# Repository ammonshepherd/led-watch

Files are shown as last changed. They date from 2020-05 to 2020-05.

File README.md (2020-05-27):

# LED Watch
My attempt at making a watch using LEDs in place of the numbers. The color of the LED denotes the hour, minute or second.

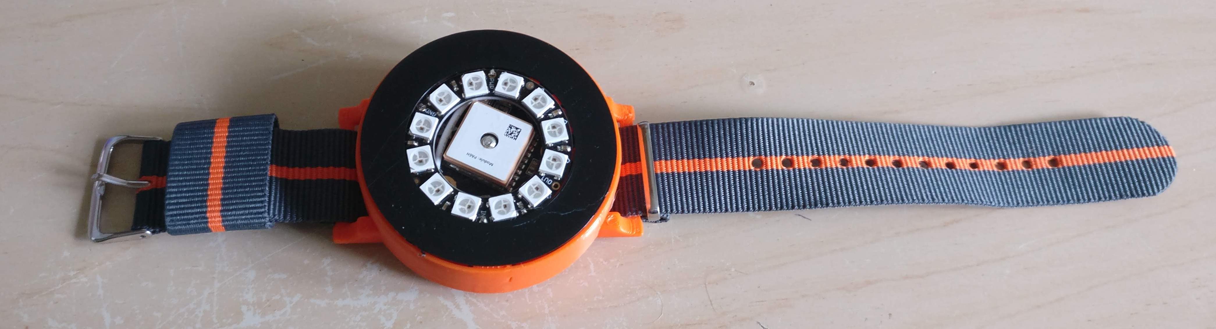
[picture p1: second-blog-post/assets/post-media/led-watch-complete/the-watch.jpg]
the watch


Here are two blog posts I wrote on the making of the watch.

## Blog Posts
* [https://scholarslab.lib.virginia.edu/blog/led-watch-making/ ](https://scholarslab.lib.virginia.edu/blog/led-watch-making/)
	* Or in this repo: [First Blog Post](/first-blog-post/2019-12-17-making-an-led-watch.md)
* [https://scholarslab.lib.virginia.edu/blog/ ](https://scholarslab.lib.virginia.edu/blog/)
	* Or in this repo: [Second Blog Post](/second-blog-post/2020-05-26-led-watch-complete.md)

## Hardware
* NeoPixel Ring
	* [https://www.adafruit.com/product/1463 ](https://www.adafruit.com/product/1463)
* FLORA Wearable
	* [https://www.adafruit.com/product/659 ](https://www.adafruit.com/product/659)
* GPS module
	* [https://learn.adafruit.com/flora-wearable-gps/downloads ](https://learn.adafruit.com/flora-wearable-gps/downloads)
* Battery and charger
	* [https://www.adafruit.com/product/1905 ](https://www.adafruit.com/product/1905)

## Resources:
* Tutorial for designing the case
	* [https://www.youtube.com/watch?v=spzZRyIX6Ic ](https://www.youtube.com/watch?v=spzZRyIX6Ic)
* Adafruit watch
	* [https://learn.adafruit.com/flora-geo-watch/the-code ](https://learn.adafruit.com/flora-geo-watch/the-code)

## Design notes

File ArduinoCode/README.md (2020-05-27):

# Arduino Code

Only the GPS_Clock code is working.

## GPS Clock

This is the code to get the time from the GPS module. It works, kind of, if
you're outside and have the luck of the Irish leprechauns on your side.

## Basic Clock

A very brief attempt to just have the time displayed programmatically. You'd
have to turn the watch on at the same time the program is designed to start,
though. Not a great idea...

## flashlight

A quick attempt to sketch out what would be required to make a button press
change the watch into a flashlight.

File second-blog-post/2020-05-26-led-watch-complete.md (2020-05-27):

LED Watch in all the Glory
*[LED Watch in all the Glory]*

This is the final post about the LED watch. (Read the first post here: [LED
Watch Making - Dec 17,
2019](https://scholarslab.lib.virginia.edu/blog/led-watch-making/)) I was able
to complete the build after *many* attempts at designing the case and few long
hours with the code. Neither are perfect. But as the saying goes, perfect is
the enemy of done.

This post will describe the design issues making the case, the code, and ideas
for developing the watch going forward.

## The Case
I designed the case using the free education license of Fusion 360. Two things
made designing the case very easy.
1. The website, [grabcad.com](grabcad.com) exists, and
   [davidrmillar](https://grabcad.com/library/adafruit-flora-wearable-v3-1)
   made a detailed model of the Adafruit Flora wearable PCB that is the basis
   of the watch. I used the model to design the posts, tabs, and other features
   in the right place and to the right scale.
2. The video tutorials of [Noe
   Ruiz](https://www.youtube.com/watch?v=GlMo6IWF6CY&list=PLjF7R1fz_OOVsMp6nKnpjsXSQ45nxfORb&index=6&t=0s)
   from Adafruit. There are a couple of his videos that were exactly what I
   needed. And a bonus were the many Fusion 360 tips and procedures that make
   any project I do going forward much better.

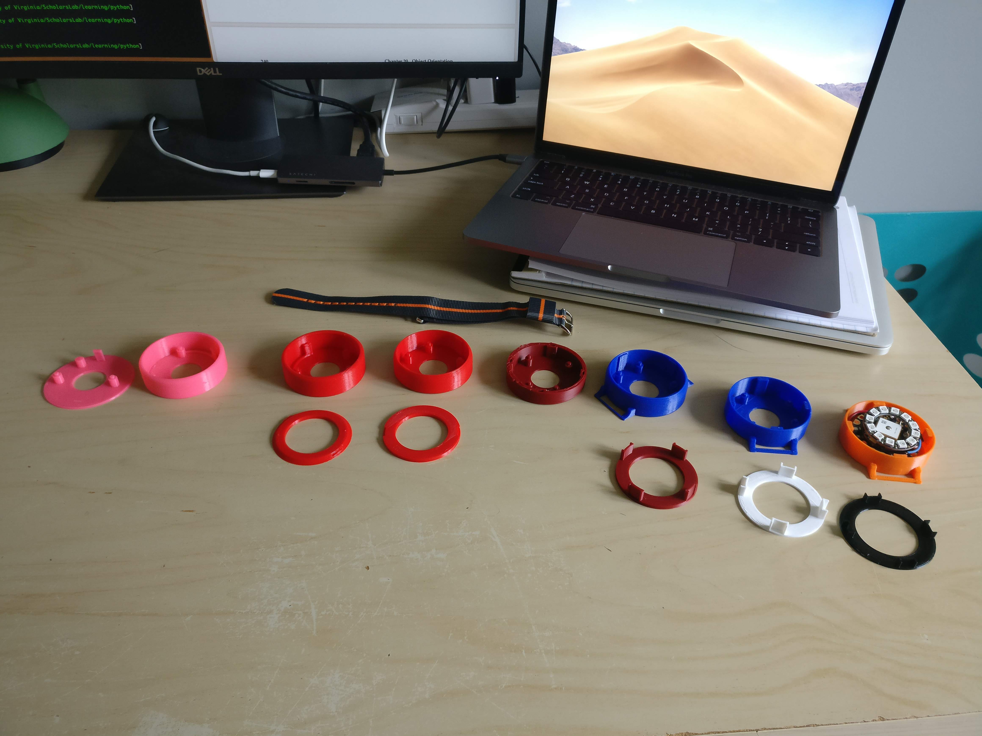
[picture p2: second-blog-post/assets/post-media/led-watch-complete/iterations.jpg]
The many iterations of the case

*[The many iterations of the case]*

Despite the model and the videos, the case took many, many iterations to get
the present state. (Notice I didn't say finished state? More on that later.)

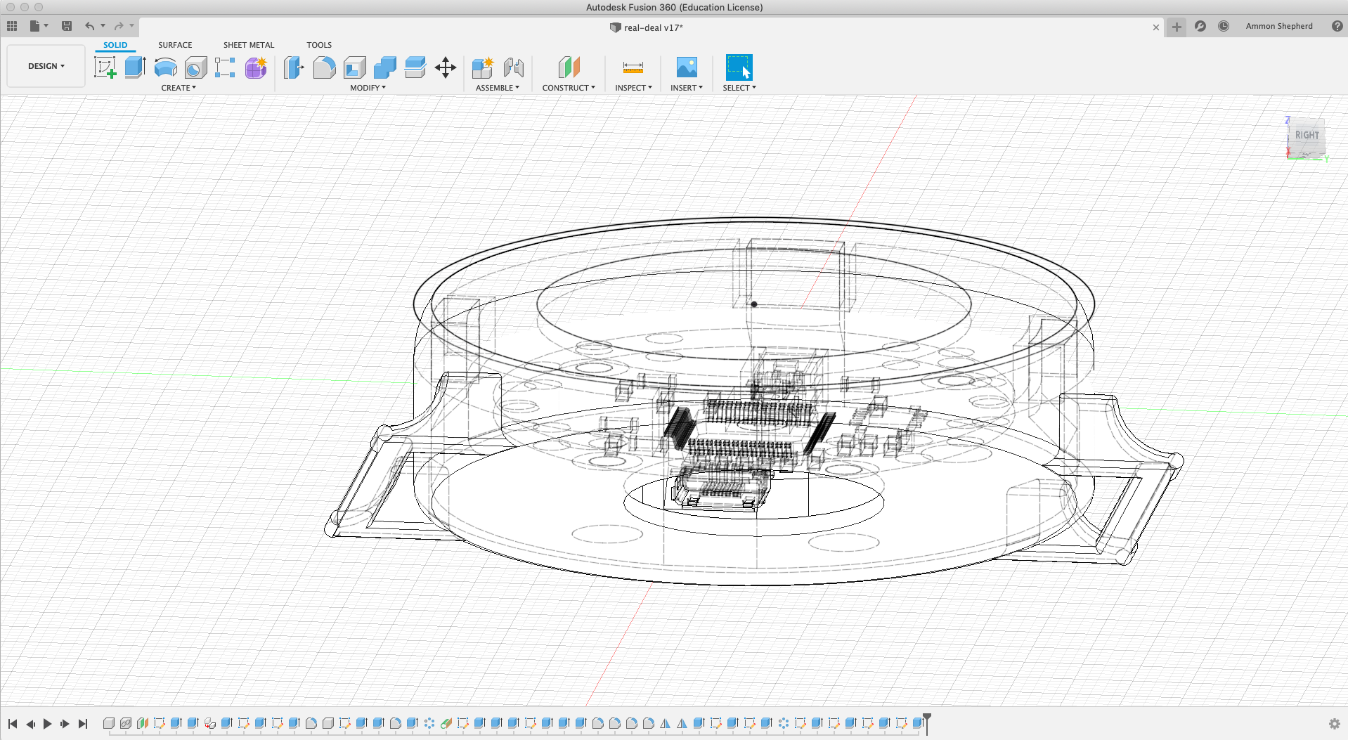
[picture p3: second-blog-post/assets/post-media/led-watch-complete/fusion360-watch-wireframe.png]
fusion 360

*[fusion 360 - wireframe]*

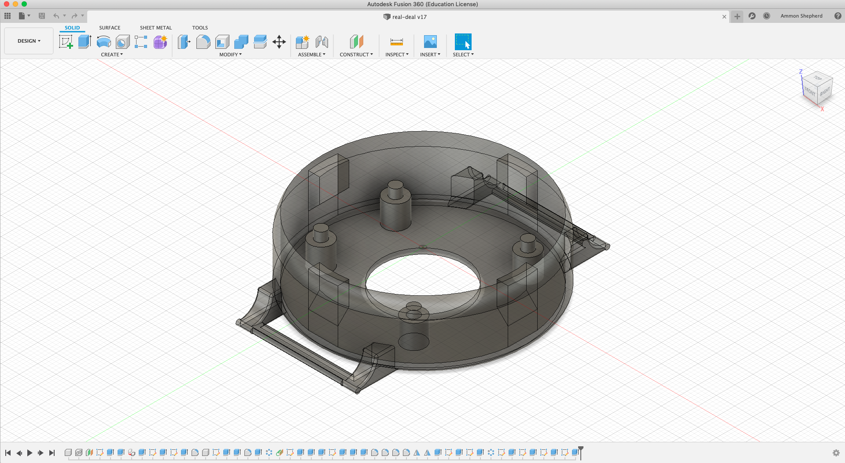
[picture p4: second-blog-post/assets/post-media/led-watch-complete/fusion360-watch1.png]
fusion 360

*[fusion 360 - watch model 1]*

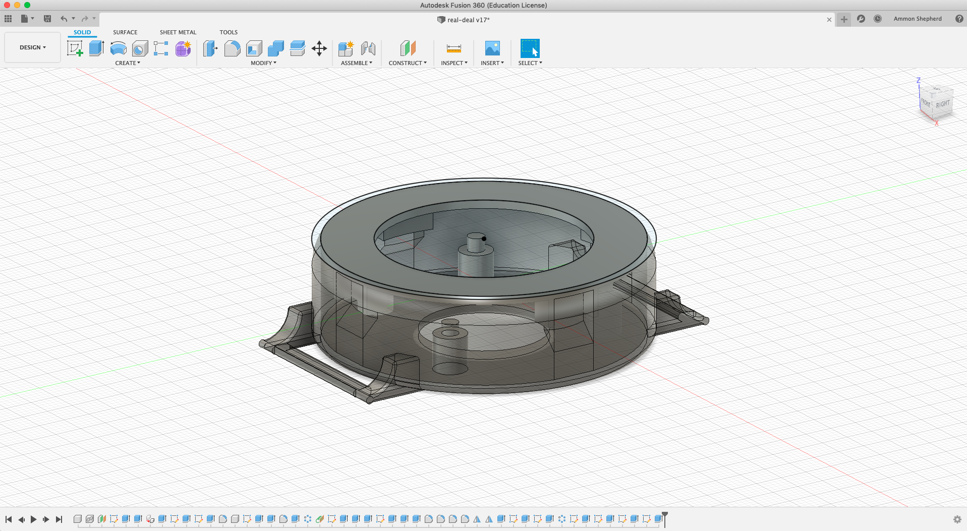
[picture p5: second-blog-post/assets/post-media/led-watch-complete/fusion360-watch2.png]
fusion 360

*[fusion 360 - watch model 2]*

The lid was difficult to design for. My first idea was to have basically a flat disc that would twist into place and be held in with a couple of notches. This didn't work out well, as my tolerances between slots and tabs were too large and the lid was not stable when in place. 

So, instead, I decided to use friction as the force to keep the lid on the case. I designed the case to have four shafts that fit over notches in the case. This provided a very tight fit.

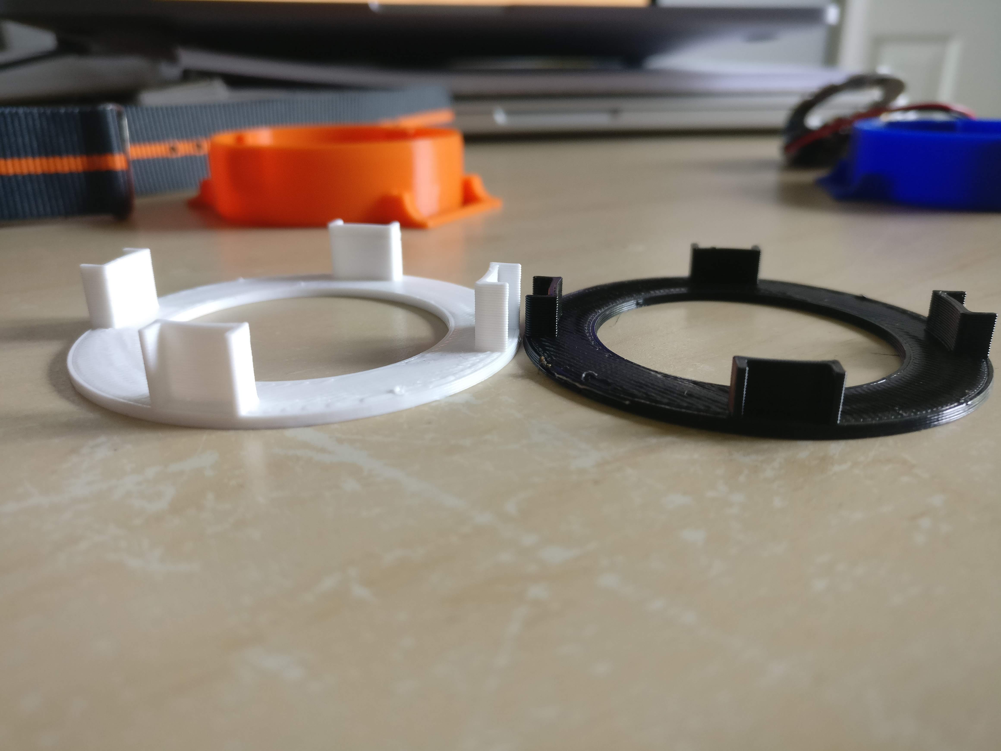
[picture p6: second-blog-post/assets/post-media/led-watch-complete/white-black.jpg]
Lid with tangs

*[Lid with tangs]*

One thing that is immediately noticeable (it was the first thing all of the kids said when they first saw it) is that the case is large! This is because the electronics inside are large. Adding a battery means the case is even larger because I had to increase the circumference to allow for the battery cables to plug into the Flora, and increase the height of the case as the battery sits under the Flora.

I had wanted the case to be more rounded, like one of those peppermint candy disks, but it 3D prints better with a flat bottom. So it ended up not as rounded as I would like it to be, but overall it looks pretty decent.

I was going to make a band out of leather, but I found one through Amazon while looking for ideas on how to attach the band to the case. It looked great and was cheap, so I went that route. The attachment part was easy to design for, but I had to keep in mind the limitations of the 3D printer, so everything had to be at a 45 degree angle and touching the bed.

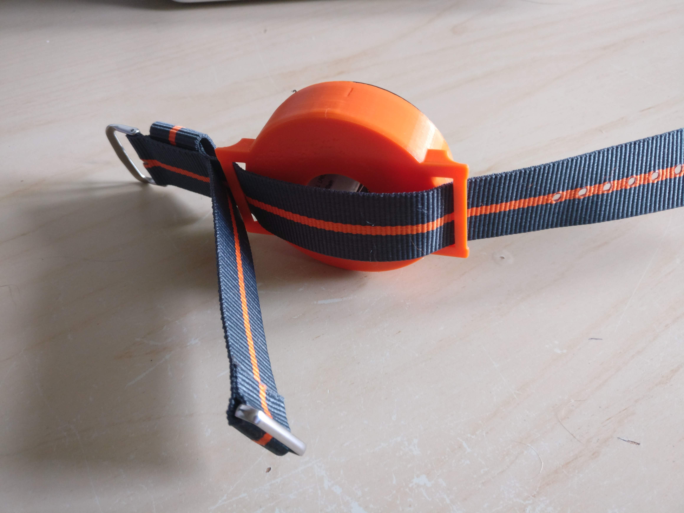
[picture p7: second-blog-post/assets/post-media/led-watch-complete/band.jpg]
Watch band

*[Watch band]*

The STL files for the case and lid are available at the GitHub repo (
[https://github.com/ammonshepherd/led-watch ](https://github.com/ammonshepherd/led-watch) ), as well as
the Fusion 360 file for your own remixing pleasure.

## The Code

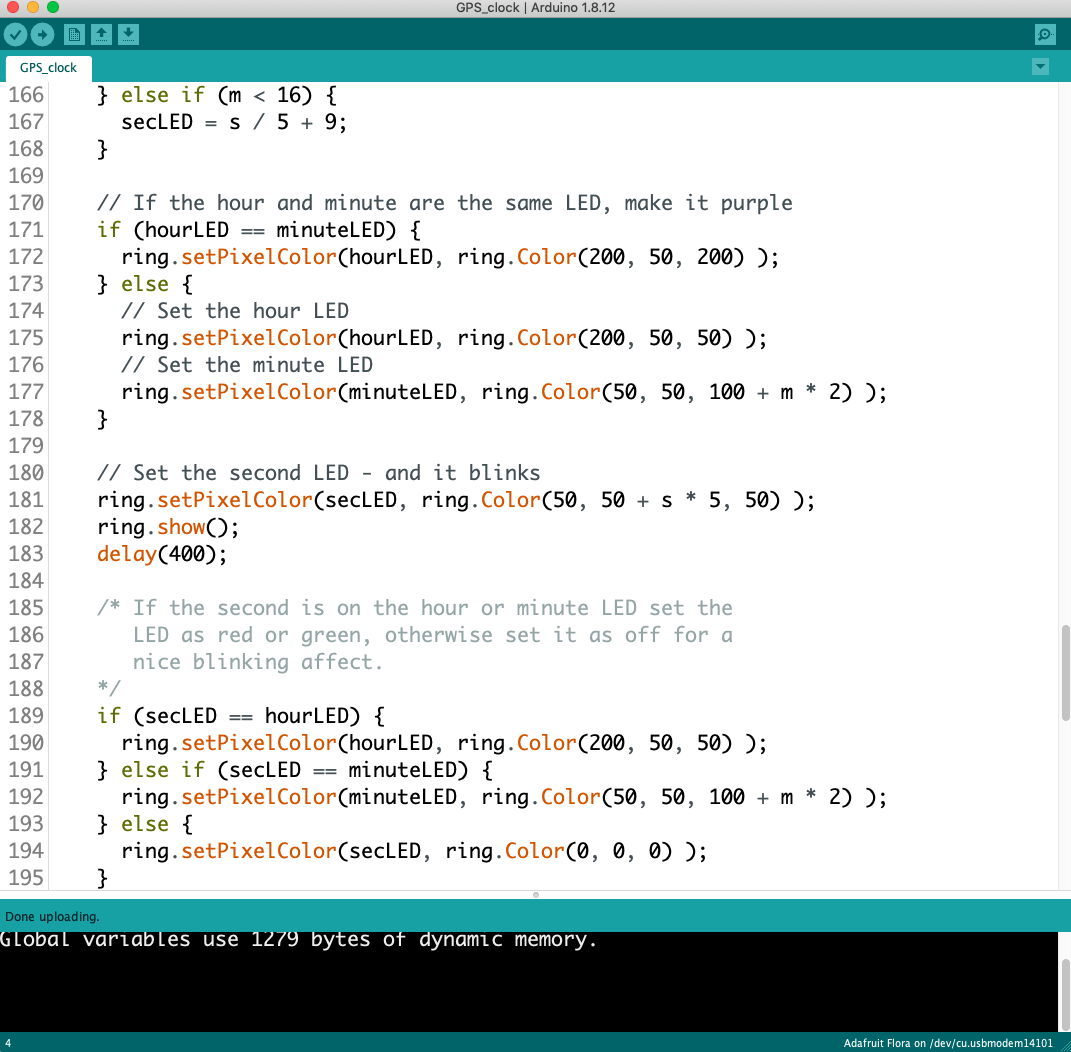
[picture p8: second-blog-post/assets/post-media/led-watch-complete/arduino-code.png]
The code

*[The code]*

The code to make the watch work never really worked 100%. The watch relies on a GPS module to get accurate time from satellites. That in itself is really awesome, but the GPS module never seemed to get a good, consistent fix on any satellites. So if the watch does show the time, it's pretty iffy. I could try to code the time all from scratch, but since the GPS module is there, I wanted it to use the hour, minute and second from the GPS in order to tell the correct time. In order to get a good fix on the satellite, the GPS needs to be outside for 5-45 minutes. Every time I had scheduled to do this, it was freezing outside and I don't want to sit in the cold, so I give up after 5 minutes. It's much warmer now, so I'll have to give it another try.

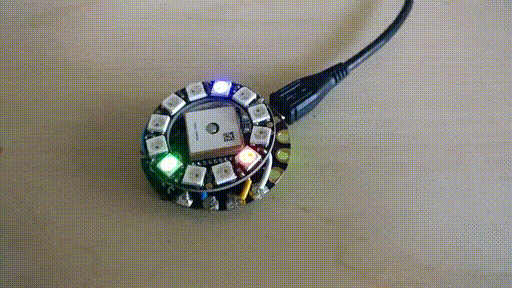
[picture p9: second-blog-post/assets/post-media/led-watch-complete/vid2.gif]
Blinking Lights


*[Blinking Lights]*

Several issues came up while coding the watch. Getting the LEDs to light at the same time was a bit counter-intuitive. I had to look at several examples, and play around with it to get multiple LEDs at the same time. It's actually pretty strait forward. Getting the seconds to blink was more tricky. They still don't blink 5 times (5 seconds) for each LED, but it's close enough.

The [code is in GitHub](https://github.com/ammonshepherd/led-watch), and pretty well commented.

## The Future

The LEDs can get really, really bright. I want to add a button to the case that
will turn the watch into a flashlight. A simple iteration of button presses
could allow for multiple brightnesses. One press to show low light, two for
medium brightness, and three for full brightness, and fourth to turn off. This
would be really easy to design change for the case, and a button is easy enough
to find and solder onto the board.

For keeping time more acurately, I'd like to find a more reliable source than a
GPS module. It's fun to think that the watch gets the time from satellites
zipping around in space, but it's not reliable, especially when indoors. 

Another idea was to tap into some sort of data stream; either social media or
government data or something of the sort. The LEDs can flash different colors
and patterns based on the data it receives. Like a circular pattern in blue when a
new comment is made on your social media platform of choice. Or (a bit more
macabre and to the times) when a new case of COVID-19 is detected in your city,
county or state, the lights could flash red, and the speed of flashing is
faster the closer it is to your location.

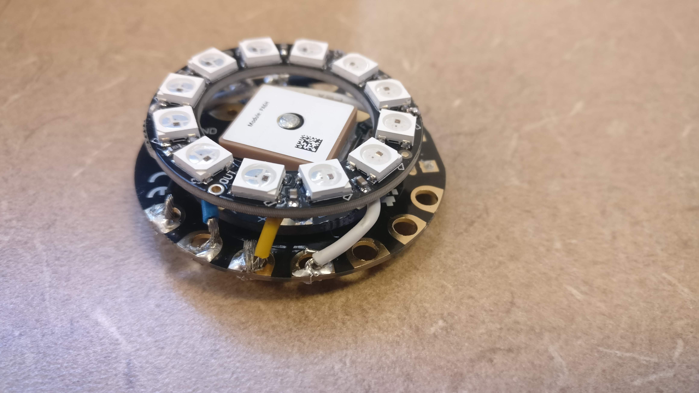
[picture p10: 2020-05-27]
first-blog-post/assets/post-media/led-watch/watch_guts.jpg

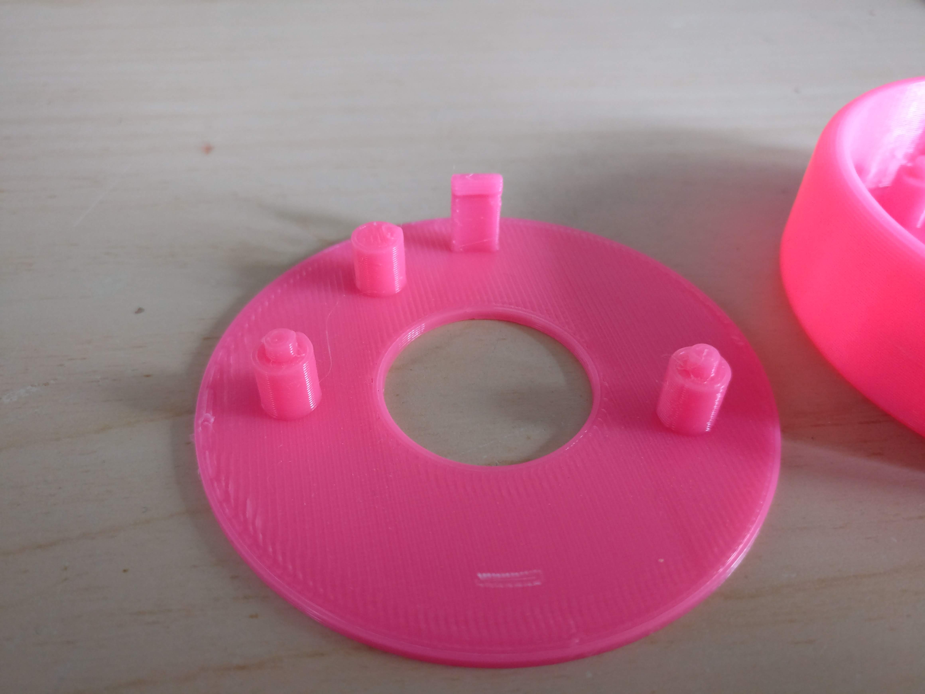
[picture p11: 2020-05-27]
second-blog-post/assets/post-media/led-watch-complete/pink-fail.jpg

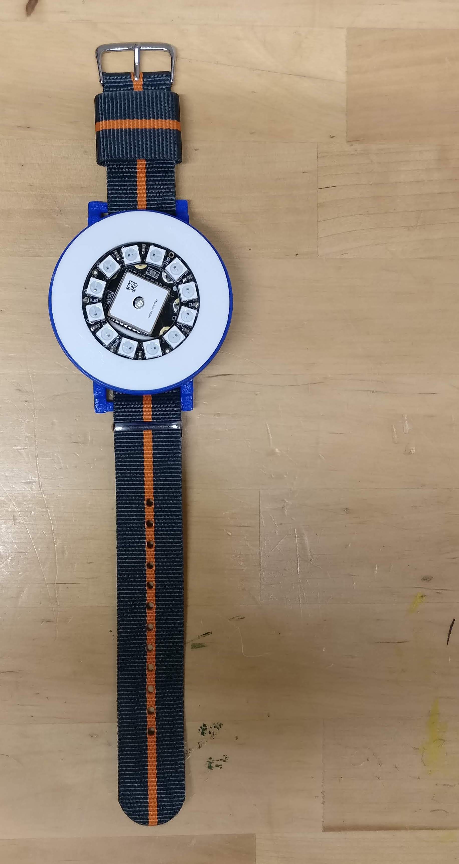
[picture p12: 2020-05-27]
second-blog-post/assets/post-media/led-watch-complete/nice-watch.jpg

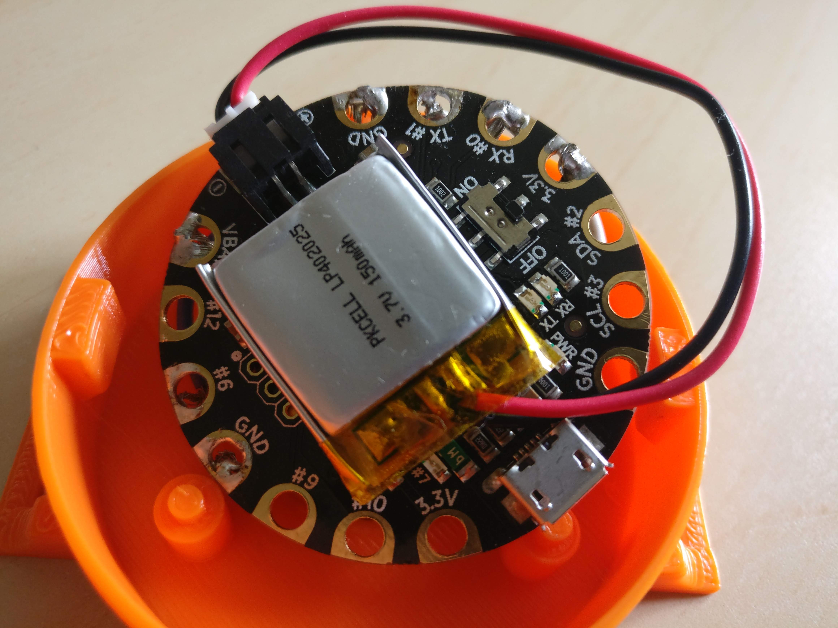
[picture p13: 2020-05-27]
second-blog-post/assets/post-media/led-watch-complete/orange-guts.jpg

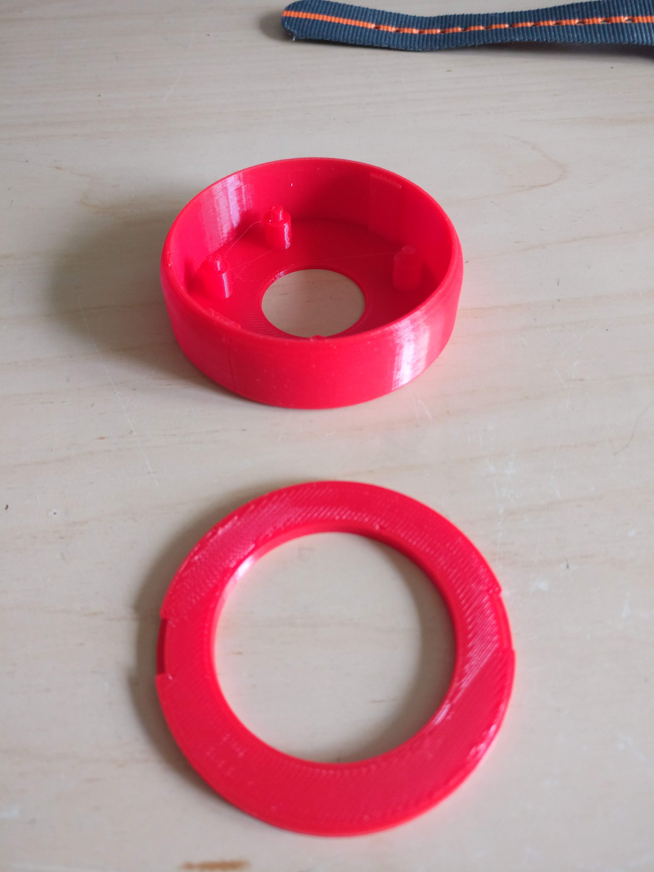
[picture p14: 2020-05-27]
second-blog-post/assets/post-media/led-watch-complete/red-red.jpg

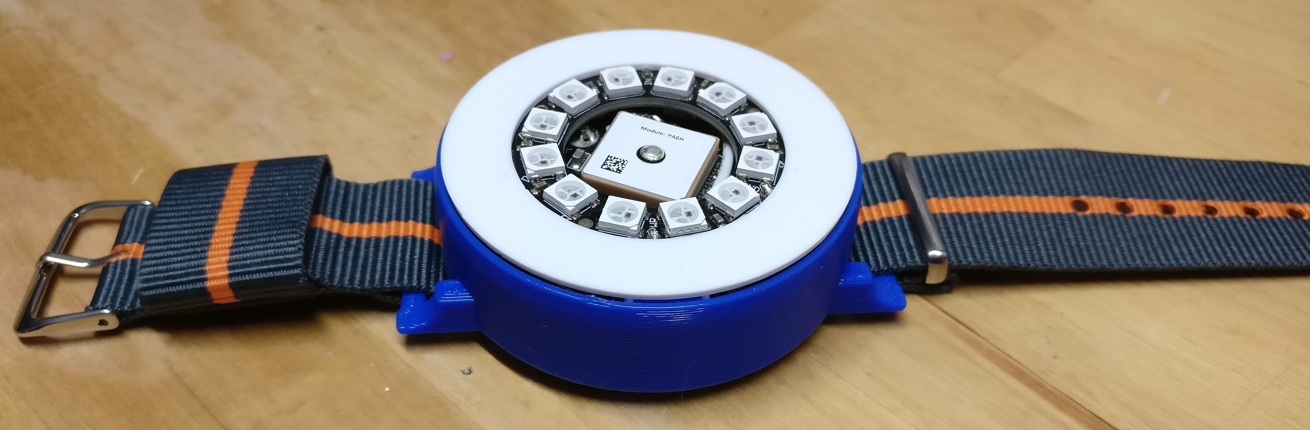
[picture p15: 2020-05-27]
second-blog-post/assets/post-media/led-watch-complete/blue-white-watch.jpg

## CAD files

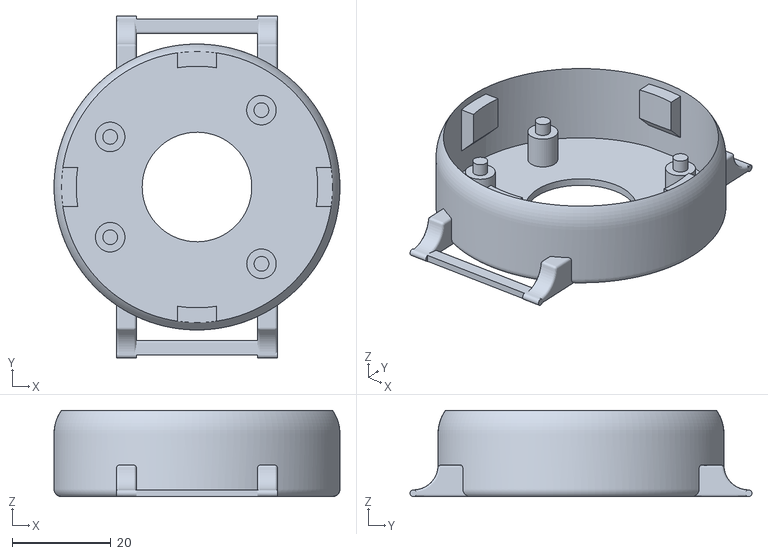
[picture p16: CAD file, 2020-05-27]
3D-Models/watch_case_v14.stl
58.0 x 69.4 x 17.5

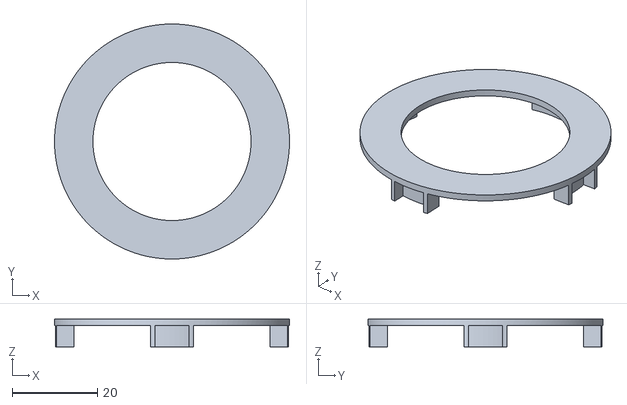
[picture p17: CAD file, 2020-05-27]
3D-Models/watch_lid_v5.stl
55.0 x 55.0 x 6.50

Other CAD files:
3D-Models/LED watch v17.f3z

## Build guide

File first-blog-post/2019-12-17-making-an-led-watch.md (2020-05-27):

# LED Watch Making

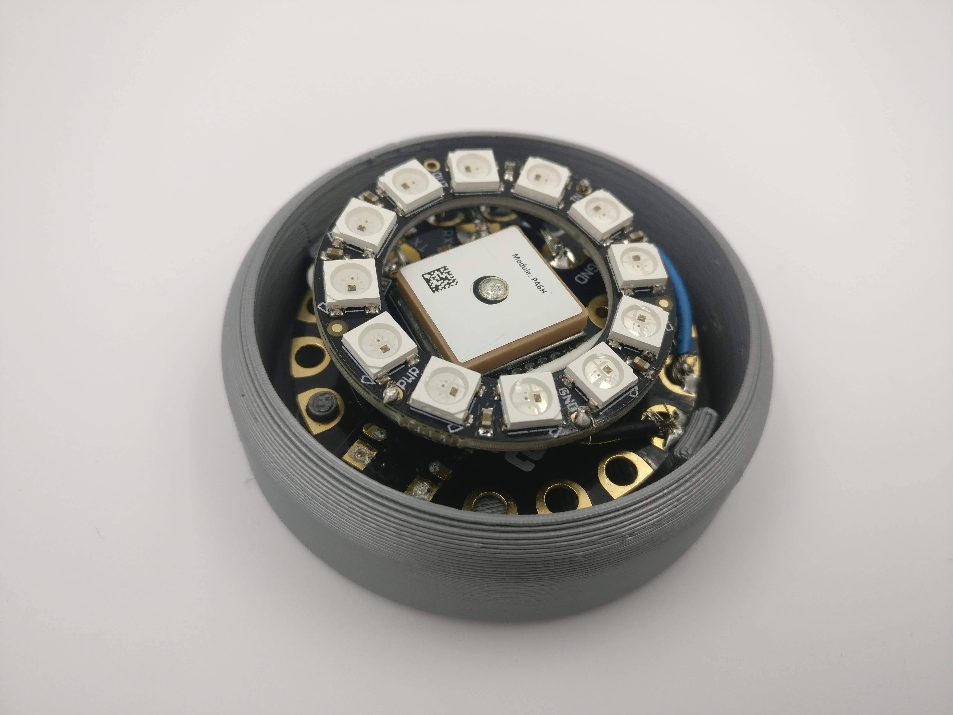
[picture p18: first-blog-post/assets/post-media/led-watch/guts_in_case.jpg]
Figure 1 First sketch of LED watch in November 2016

*[A watch?]*

## The Idea
This project started as an idea over three years ago when I saw a watch someone was wearing at a conference I was attending, [ISAM 2016](https://project-manus.mit.edu/courses-and-symposiums), the International Symposium of Academic Makerspaces. The watch I saw was a wooden square. The face was simply holes at each hour, with LED lights underneath to illuminate the hours, minutes and seconds. I figured that would be an easy design to replicate.
 
First sketch of LED watch in November 2016
*[First sketch of an LED watch in November 2016]*

An attempt later the next year ended in failure, as the LEDs and boards I purchased proved to be unresponsive and too difficult to get working. The boards did not solder together well, and the code was hard to write with little documentation.

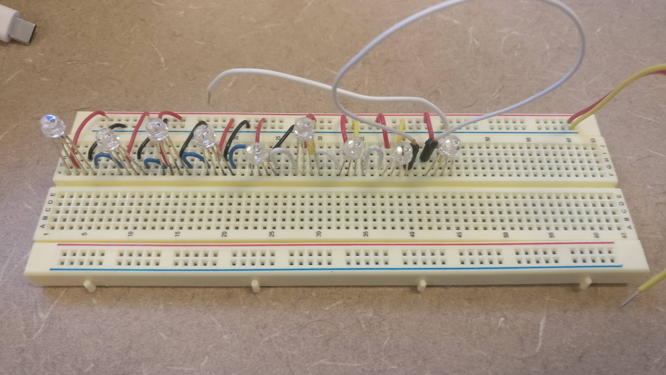
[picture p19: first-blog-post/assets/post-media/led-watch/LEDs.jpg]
First attempt with LEDs

*[First attempt with just LEDs]*

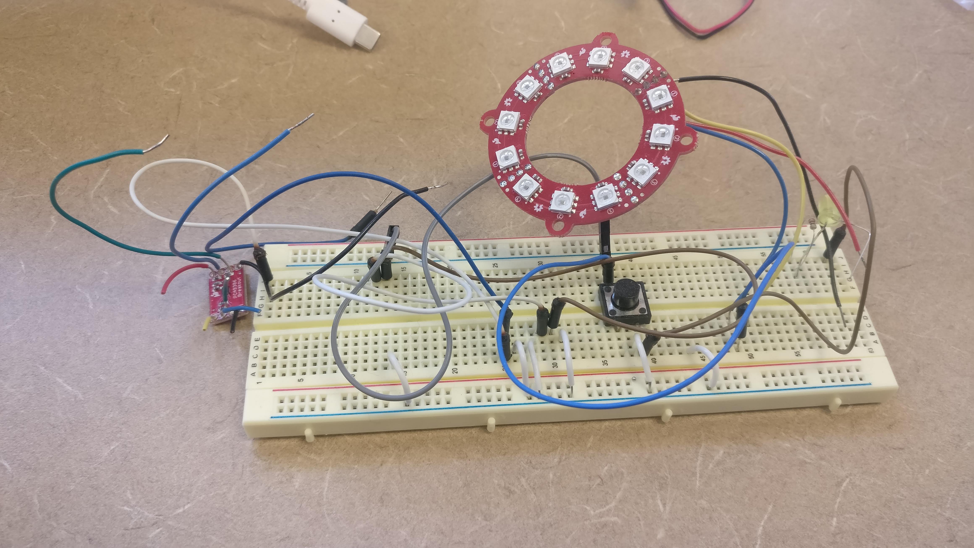
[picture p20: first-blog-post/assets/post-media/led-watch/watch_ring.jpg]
Attempt with failing parts

*[2nd attempt...]*

This time, I was able to find some parts from Adafruit.com that simplified the project immensely. They even had a tutorial for creating a watch! [https://learn.adafruit.com/flora-geo-watch/](https://learn.adafruit.com/flora-geo-watch/)

## The Guts
The process of soldering the pieces together was quite simple. The only problem here was getting the wires soldered on in the right lengths and oriented in the right way for the boards to sit on top of each other correctly. I did also run into an issue where I had wrapped the wire around the holes in the board, and then soldered them in place. This proved to be an issue when trying to make a case that fit the dimensions of the board. I had to clip the excess solder and wires from the edge of the board.

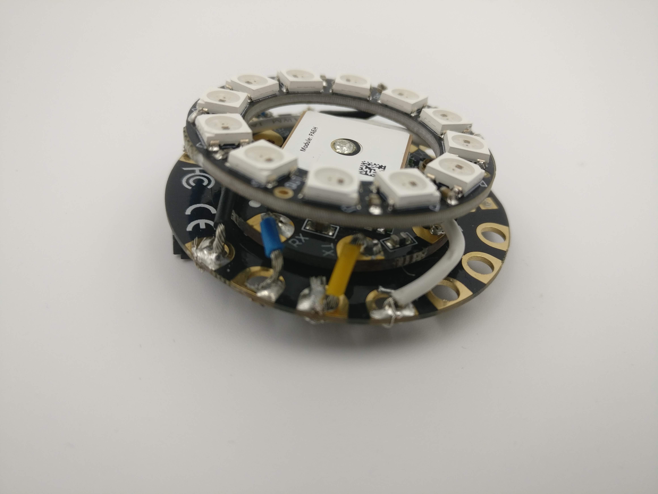
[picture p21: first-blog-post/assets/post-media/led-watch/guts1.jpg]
The assembled FLORA, GPS module, and NeoPixel Ring

*[The guts of the watch, assembled FLORA, GPS module, and NeoPixel Ring]*

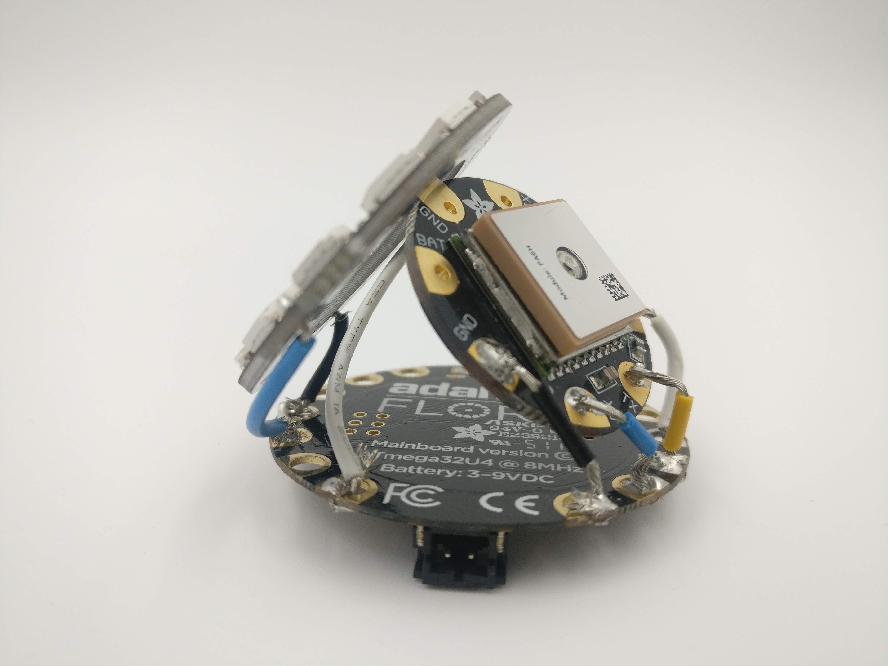
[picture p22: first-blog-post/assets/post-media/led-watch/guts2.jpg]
The assembled FLORA, GPS module, and NeoPixel Ring, exploded view 1

*[The assembled FLORA, GPS module, and NeoPixel Ring, exploded view 1]*

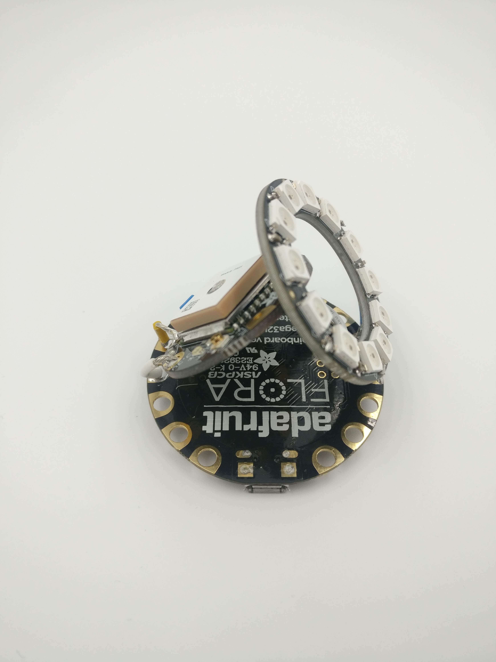
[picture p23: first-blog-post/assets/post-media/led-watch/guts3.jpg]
The assembled FLORA, GPS module, and NeoPixel Ring, exploded view 2

*[The assembled FLORA, GPS module, and NeoPixel Ring, exploded view 2]*

## The Code
The Arduino code was pretty simple. I started by writing generic code that would turn on a certain LED if a number passed to a function was within a certain range. For example, LED 0 turns on when the number is between 0 and 4 (inclusive), LED 1 turns on when the number is between 5 and 9 (inclusive). With that code figured out, I read documentation and examples to pull the hour, minute, and second from the GPS sensor. Then I plugged that value from the GPS sensor into the function explained above. That easily generates a green light for second, red light for the minute and blue light for the hour. The second and minute are set in increments of five. So each LED is in turn illuminated for five seconds green. This proved to be a work in progress, too, because the GPS unit did not get a good reading on the satellites, and did not update to the correct time.

See below for the code so far, or here: [https://github.com/ammonshepherd/led-watch/tree/master/watch_code](https://github.com/ammonshepherd/led-watch/tree/master/watch_code)

## The Case
With the code (mostly) working correctly. I started designing the case. The original idea of a wood case was too much to handle for the moment. So I went with a 3D printed case. I designed the case in Fusion 360. The original design is a cylinder with cut outs for the micro-USB port and the JST port. I went through eight iterations before deciding that the entire thing should be encompassed in the case, with no holes, in order to better support the PCB and to better incorporate the battery. I found a tutorial on Youtube that shows how to create the support structure that I’m looking for, so I’ll be following that to design a better case, while also incorporating a way to include a watch strap.

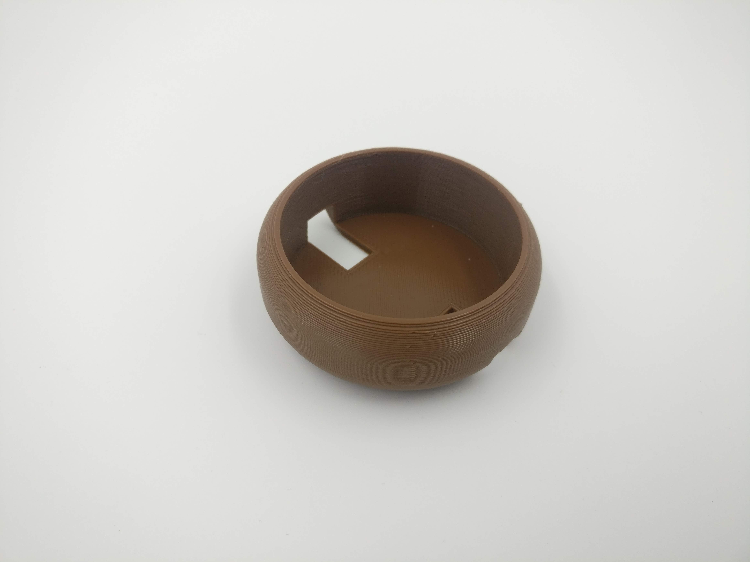
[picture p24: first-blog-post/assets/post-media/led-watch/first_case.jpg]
The first case

*[First case attempt]*

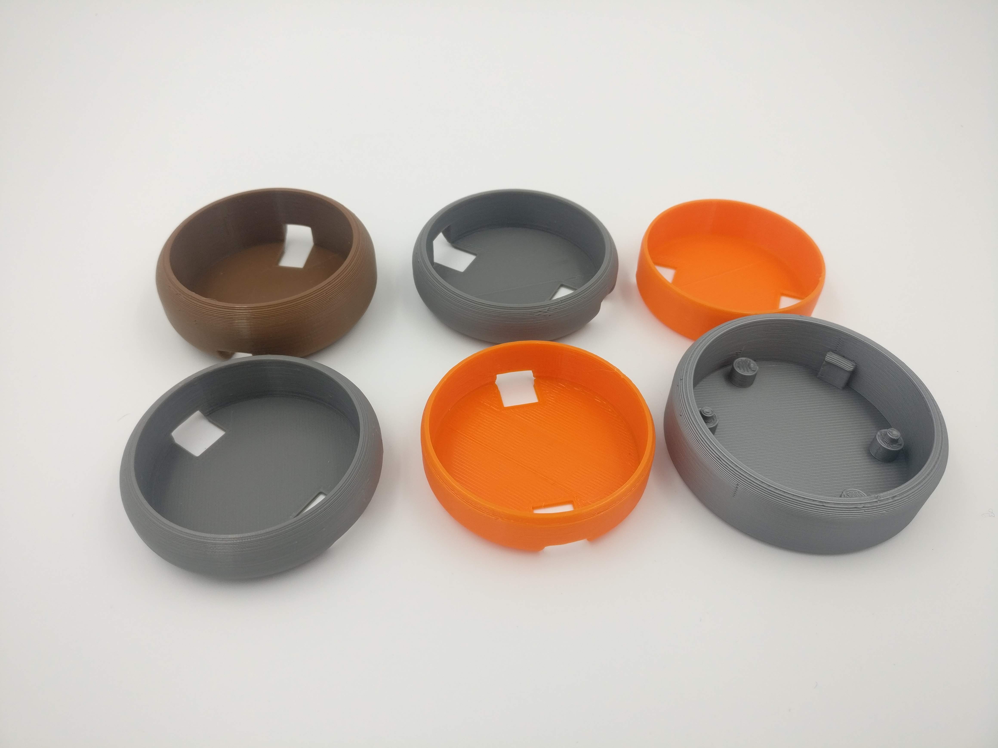
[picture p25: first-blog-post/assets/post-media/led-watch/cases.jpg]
Different iterations of the case

*[Various itterations of the case]*
 
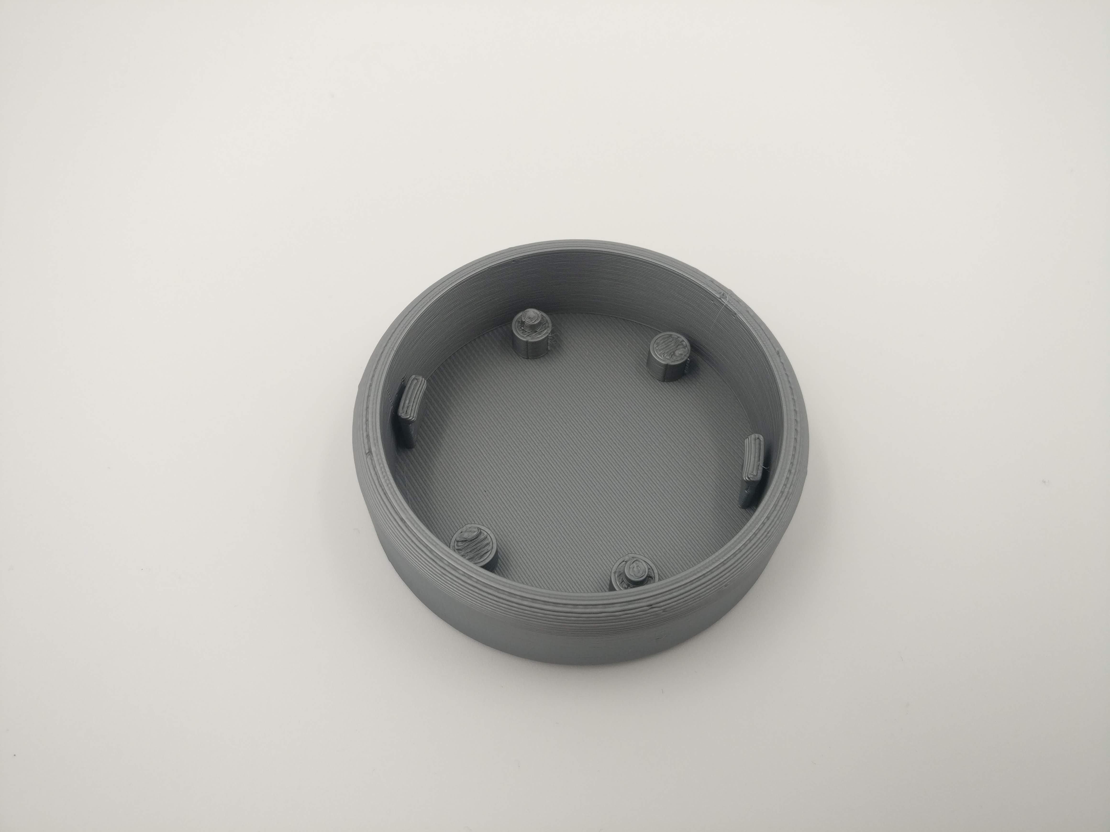
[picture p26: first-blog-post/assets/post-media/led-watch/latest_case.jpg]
the latest case

*[The latest version of the case]*

The next steps are to:

1.	Fix the code so it accurately tells time and gets the correct time from the GPS module.
2.	Design and make a better case, with acrylic top.
3.	Design and create a watch band.

## Resources:

* Adafruit watch
	* [https://learn.adafruit.com/flora-geo-watch/the-code](https://learn.adafruit.com/flora-geo-watch/the-code)
* NeoPixel Ring
	* [https://www.adafruit.com/product/1463](https://www.adafruit.com/product/1463)
* FLORA Wearable
	* [https://www.adafruit.com/product/659](https://www.adafruit.com/product/659)
* GPS module
	* [https://learn.adafruit.com/flora-wearable-gps/downloads](https://learn.adafruit.com/flora-wearable-gps/downloads)
* Battery and charger
	* [https://www.adafruit.com/product/1905](https://www.adafruit.com/product/1905)
* Tutorial for designing the case
	* [https://www.youtube.com/watch?v=spzZRyIX6Ic](https://www.youtube.com/watch?v=spzZRyIX6Ic)

## Arduino Code

```
/*
   Author: Ammon Shepherd
   Date: November 21, 2019

   Display the time on an Adafruit NeoPixel Ring with Adafruit GPS module and Flora

   Parts:
     - NeoPixel Ring: https://www.adafruit.com/product/1643
     - Flora Wearable Ultimate GPS Module: https://www.adafruit.com/product/1059
     - Flora Main Board: https://www.adafruit.com/product/659

    NeoPixel Ring Pin Layout:
     Time : PIN
     - 12 : 0
     - 01 : 1
     - 02 : 2
     - 03 : 3
     - 04 : 4
     - 05 : 5
     - 06 : 6
     - 07 : 7
     - 08 : 8
     - 09 : 9
     - 10 : 10
     - 11 : 11

*/

#include <Adafruit_NeoPixel.h>
#include <Adafruit_GPS.h>

#define GPSSerial Serial1
#define LED_PIN 6
#define LED_COUNT 12

Adafruit_NeoPixel strip(LED_COUNT, LED_PIN, NEO_GRB + NEO_KHZ800);

uint32_t SECONDS_COLOR = strip.Color(0, 230, 0);
uint32_t MINUTES_COLOR = strip.Color(230, 0, 0);
uint32_t HOURS_COLOR = strip.Color(0, 0, 230);

Adafruit_GPS GPS(&GPSSerial);
// Set to false to not send serial data
#define GPSECHO true

uint32_t timer = millis();

void setup() {

  Serial.begin(115200);
  Serial.println("LED Watch Code");

  // Start the GPS stuff
  GPS.begin(9600);
  GPS.sendCommand(PMTK_SET_NMEA_OUTPUT_RMCONLY);
  GPS.sendCommand(PMTK_SET_NMEA_UPDATE_1HZ);
  GPS.sendCommand(PGCMD_ANTENNA);
  delay(1000);
  GPSSerial.println(PMTK_Q_RELEASE);

  // Start the LED ring off
  //Serial.begin(9600);
  strip.begin();
  strip.show();
  strip.setBrightness(3);

}

void loop() {

  char c = GPS.read();

  // debug info, set above
  if (GPSECHO) {
    if (c) {
      Serial.print(c);
    }

    Serial.print("hour: ");
    Serial.println(GPS.hour, DEC);

    Serial.print("minute: ");
    Serial.println(GPS.minute, DEC);

    Serial.print("second: ");
    Serial.println(GPS.seconds, DEC);

    Serial.print("day: ");
    Serial.println(GPS.day, DEC);

    Serial.print("month: ");
    Serial.println(GPS.month, DEC);

    Serial.print("year: ");
    Serial.println(GPS.year, DEC);

    if (GPS.newNMEAreceived()) {
      Serial.println(GPS.lastNMEA());
      if (!GPS.parse(GPS.lastNMEA())) {
        return;
      }
    }

  }

  show_time(GPS.hour, "hours");
  show_time(GPS.minute, "minutes");
  show_time(GPS.seconds, "seconds");

  /*
    for (int s = 0; s < 60; s++) {
      seconds(s);
      delay(1000);
    }
  */

}

void show_time(int t, String color) {
  int led;
  if ( t >= 0 and t < 5) {
    led = 0;
  }
  if ( t > 4 and t < 10 ) {
    led = 1;
  }
  if ( t > 9 and t < 15 ) {
    led = 2;
  }
  if ( t > 14 and t < 20 ) {
    led = 3;
  }
  if ( t > 19 and t < 25 ) {
    led = 4;
  }
  if ( t > 24 and t < 30 ) {
    led = 5;
  }
  if ( t > 29 and t < 35 ) {
    led = 6;
  }
  if ( t > 34 and t < 40 ) {
    led = 7;
  }
  if ( t > 39 and t < 45 ) {
    led = 8;
  }
  if ( t > 44 and t < 50 ) {
    led = 9;
  }
  if ( t > 49 and t < 55 ) {
    led = 10;
  }
  if ( t > 54) {
    led = 11;
  }

  strip.clear();
  uint32_t display_color;
  if (color == "hours") {
    display_color = HOURS_COLOR;
  } else if (color == "minutes") {
    display_color = MINUTES_COLOR;
  } else if (color == "seconds") {
    display_color = SECONDS_COLOR;
  }
  strip.setPixelColor(led, display_color);
  strip.show();
}
```

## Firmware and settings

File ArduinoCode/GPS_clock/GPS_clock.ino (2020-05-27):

/* GPS LED Watch
 * author: Ammon Shepherd
 * date: May 2020
 * License: use it however you want, just attribute back to me.
 *
 * Much of the GPS code is from Adafruit GPS 
 * https://github.com/adafruit/Adafruit_GPS/blob/master/examples/GPS_HardwareSerial_Timing/GPS_HardwareSerial_Timing.ino
 *
*/
#include <Adafruit_GPS.h>

#define GPSSerial Serial1

Adafruit_GPS GPS(&GPSSerial);

// Set GPSECHO to 'false' to turn off echoing the GPS data to the Serial console
// Set to 'true' if you want to debug and listen to the raw GPS sentences
#define GPSECHO true

uint32_t timer = millis();

/* LED Ring code

*/
#include <Adafruit_NeoPixel.h>
#define LED_PIN 6
#define LED_COUNT 12

Adafruit_NeoPixel ring(LED_COUNT, LED_PIN, NEO_GRB + NEO_KHZ800);


void setup() {
  // connect at 115200 so we can read the GPS fast enough and echo without
  // dropping chars also spit it out
  Serial.begin(115200);
  //Serial.println("Adafruit GPS library basic test!");

  // 9600 NMEA is the default baud rate for Adafruit MTK GPS's- some use 4800
  GPS.begin(9600);
  GPS.sendCommand(PMTK_SET_NMEA_OUTPUT_RMCONLY);
  GPS.sendCommand(PMTK_SET_NMEA_UPDATE_100_MILLIHERTZ); // 10 second update time
  // Request updates on antenna status, comment out to keep quiet
  GPS.sendCommand(PGCMD_ANTENNA);
  delay(1000);
  // Ask for firmware version
  //GPSSerial.println(PMTK_Q_RELEASE);

  ring.begin();
  ring.setBrightness(3);
}

void loop() // run over and over again
{
  ring.clear();

  // read data from the GPS in the 'main loop'
  char c = GPS.read();
  if (GPSECHO)
    if (c)
      //Serial.print(c);
      // if a sentence is received, we can check the checksum, parse it...
      if (GPS.newNMEAreceived()) {
        // a tricky thing here is if we print the NMEA sentence, or data
        // we end up not listening and catching other sentences!
        // so be very wary if using OUTPUT_ALLDATA and trytng to print out data
        //Serial.println(GPS.lastNMEA()); // this also sets the newNMEAreceived()
        // flag to false
        if (!GPS.parse(GPS.lastNMEA())) // this also sets the newNMEAreceived() flag
          // to false
          return; // we can fail to parse a sentence in which case we should just
        // wait for another
      }
  // if millis() or timer wraps around, we'll just reset it
  if (timer > millis())
    timer = millis();


  // approximately every 2 seconds or so, random intervals, print out the
  // current stats
  static unsigned nextInterval = 2000;
  if (millis() - timer > nextInterval) {
    timer = millis(); // reset the timer
    nextInterval = 1500 + random(1000);
    // Time in seconds keeps increasing after we get the NMEA sentence.
    // This estimate will lag real time due to transmission and parsing delays,
    // but the lag should be small and should also be consistent.
    int s = GPS.seconds + GPS.milliseconds / 1000. + GPS.secondsSinceTime();
    int m = GPS.minute;
    int h = GPS.hour;

    while (s > 60) {
      s -= 60;
      m++;
    }
    while (m > 60) {
      m -= 60;
      h++;
    }
    while (h > 24) {
      h -= 24;

    }

    // Convert hours from 0-24 to 1-12
    if (h > 12) {
      h -= 12;
    } else if (h = 0) {
      h = 12;
    }

    /* LED pin 9 is at the 12 hour spot. LED pin 3 is at
       the 6 hour spot.

       The hour is from GPS.hour which is 4 hours ahead
       of EST, so the pin number compensates for EST by
       subtracting 4.

       Hour | PIN
          1 = 6
          2 = 5
          3 = 8
          4 = 9
          5 = 10
          6 = 11
          7 = 0
          8 = 1
          9 = 2
         10 = 3
         11 = 4
         12 = 5
    */
    int hourLED = 6;
    if (h > 6) {
      hourLED = h - 7;
    } else if (h < 7) {
      hourLED = h + 5;
    }

    /* The minute LED can be generated easily by
        dividing m by 5 (m/5 = led pin) since
        (60/5) is a number between 1-12, but we need
        to rotate the numbers since pin 9 is at the
        12 hour mark.

        Minute | Pin
           1-5 = 9
          6-10 = 10
         11-15 = 11
         16-20 = 0
         21-25 = 1
         26-30 = 2
         31-35 = 3
         36-40 = 4
         41-45 = 5
         46-50 = 6
         51-55 = 7
         56-60 = 8
    */
    int minuteLED = 0;
    if (m > 15) {
      minuteLED = m / 5 - 3;
    } else if (m < 16 ) {
      minuteLED = m / 5 + 9;
    }


    // Seconds are the same as minutes, but they go around faster.
    int secLED = 0;
    if (s > 15) {
      secLED = s / 5 - 3;
    } else if (m < 16) {
      secLED = s / 5 + 9;
    }

    // If the hour and minute are the same LED, make it purple
    if (hourLED == minuteLED) {
      ring.setPixelColor(hourLED, ring.Color(200, 50, 200) );
    } else {
      // Set the hour LED
      ring.setPixelColor(hourLED, ring.Color(200, 50, 50) );
      // Set the minute LED
      ring.setPixelColor(minuteLED, ring.Color(50, 50, 100 + m * 2) );
    }

    // Set the second LED - and it blinks
    ring.setPixelColor(secLED, ring.Color(50, 50 + s * 5, 50) );
    ring.show();
    delay(400);

    /* If the second is on the hour or minute LED set the
       LED as red or green, otherwise set it as off for a
       nice blinking affect.
    */
    if (secLED == hourLED) {
      ring.setPixelColor(hourLED, ring.Color(200, 50, 50) );
    } else if (secLED == minuteLED) {
      ring.setPixelColor(minuteLED, ring.Color(50, 50, 100 + m * 2) );
    } else {
      ring.setPixelColor(secLED, ring.Color(0, 0, 0) );
    }

    // Light up the LEDs based on the colors set above.
    ring.show();

    // Uncomment to show GPS data
    //details(h, m, s);
  }
}


void details(int h, int m, int s) {
  Serial.print("\n\nTime: ");
  if (h < 10)
    Serial.print("0");
  Serial.print(h, DEC);
  Serial.print(':');
  if (m < 10)
    Serial.print("0");
  Serial.print(m, DEC);
  Serial.print(':');
  if (s < 10)
    Serial.print("0");
  Serial.println(s, 3);
  Serial.print("Fix: ");
  Serial.print((int)GPS.fix);
  Serial.print(" quality: ");
  Serial.println((int)GPS.fixquality);
  Serial.print("Time [s] since last fix: ");
  Serial.println(GPS.secondsSinceFix(), 3);
  Serial.print("    since last GPS time: ");
  Serial.println(GPS.secondsSinceTime(), 3);
  Serial.print("    since last GPS date: ");
  Serial.println(GPS.secondsSinceDate(), 3);
  if (GPS.fix) {
    Serial.print("Location: ");
    Serial.print(GPS.latitude, 4);
    Serial.print(GPS.lat);
    Serial.print(", ");
    Serial.print(GPS.longitude, 4);
    Serial.println(GPS.lon);
    Serial.print("Speed (knots): ");
    Serial.println(GPS.speed);
    Serial.print("Angle: ");
    Serial.println(GPS.angle);
    Serial.print("Altitude: ");
    Serial.println(GPS.altitude);
    Serial.print("Satellites: ");
    Serial.println((int)GPS.satellites);
  }

}

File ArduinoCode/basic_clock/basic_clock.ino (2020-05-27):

/*
   Author: Ammon Shepherd
   Date: 29 April 2020

   Basic Clock Functionality

   Parts:
     - NeoPixel Ring: https://www.adafruit.com/product/1643
     - Flora Wearable Ultimate GPS Module: https://www.adafruit.com/product/1059
     - Flora Main Board: https://www.adafruit.com/product/659

   NeoPixel Ring LED Layout:
     Time : LED #
     - 12 : 0
     - 01 : 1
     - 02 : 2
     - 03 : 3
     - 04 : 4
     - 05 : 5
     - 06 : 6
     - 07 : 7
     - 08 : 8
     - 09 : 9
     - 10 : 10
     - 11 : 11


*/
#include <Adafruit_NeoPixel.h>
#define LED_PIN 6
#define LED_COUNT 12


Adafruit_NeoPixel ring(LED_COUNT, LED_PIN, NEO_GRB + NEO_KHZ800);

void setup() {
  ring.begin();
  ring.setBrightness(3);
  Serial.begin(9600);
}

void loop() {
  minutes();
}

void minutes() {
  int red, green, blue;
  red = 200;
  green = 50;
  blue = 50;
  for ( int m = 0; m < LED_COUNT; m++ ){
    ring.setPixelColor(m, ring.Color(red, green, blue) );
    ring.show();
    seconds();
    delay(60000 * 5);
    
  }
}

/* Show the seconds (green)
 *  Each LED is five seconds, so it blinks 5 times
 */
void seconds() {
  int red, green, blue;
  // Loop through all the LEDs
  for ( int p = 0; p < LED_COUNT; p++ ) {
    // 5 times for each LED
    for ( int c = 1; c <= 5; c++ ) {
      // turn off all the pixels first
      //ring.clear();
      // Show no light for 200ths of a second
      ring.setPixelColor(p, ring.Color(0,0,0));
      ring.show();
      delay(200);
      
      // Set the color values, the brightness increases each second
      red = 10 + c * 4;
      green = 50 + c * 37;
      blue = 10 + c * 6; 
      ring.setPixelColor(p, ring.Color(red, green, blue));
      ring.show();
      delay(800);
    }
  }
}

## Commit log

2019-12-17 more case versions and a README
    [LED Watch v8.stl, snap-fit-case v5.stl, snap-fit-case v7.stl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]
2020-05-27 Add blog posts, images, files
    [LED Watch v1.stl, LED Watch v2.stl, LED Watch v3.stl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]
